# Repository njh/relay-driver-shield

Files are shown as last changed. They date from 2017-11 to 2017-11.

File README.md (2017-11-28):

Relay Driver Shield
===================

An Arduino shield for controlling four 12v relays.
The schematic and PCB layout were created using [KiCad](http://kicad-pcb.org/).

While it is designed for relays, it can be used for powering anything
that requires a bit more current or voltage.

| Arduino Pin | Function  |
|---|---|
| `D5` | Relay 1 |
| `D6` | Relay 2 |
| `D7` | Relay 3 |
| `D8` | Relay 4 |

The output voltage is determined by the input voltage on the Arduino Board - the `VIN` pin.

Schematic
---------

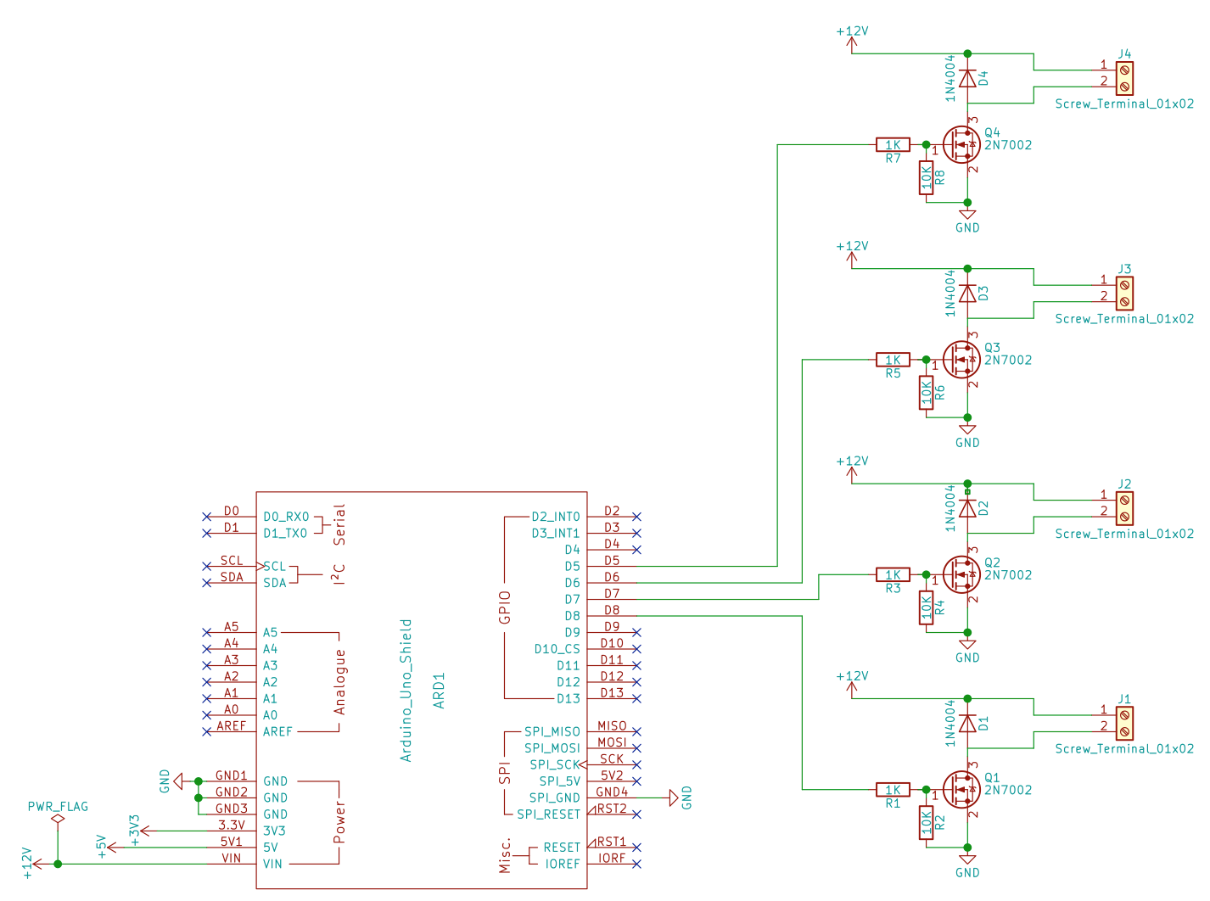
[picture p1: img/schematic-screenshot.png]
Schematic Screenshot


PCB Layout
----------

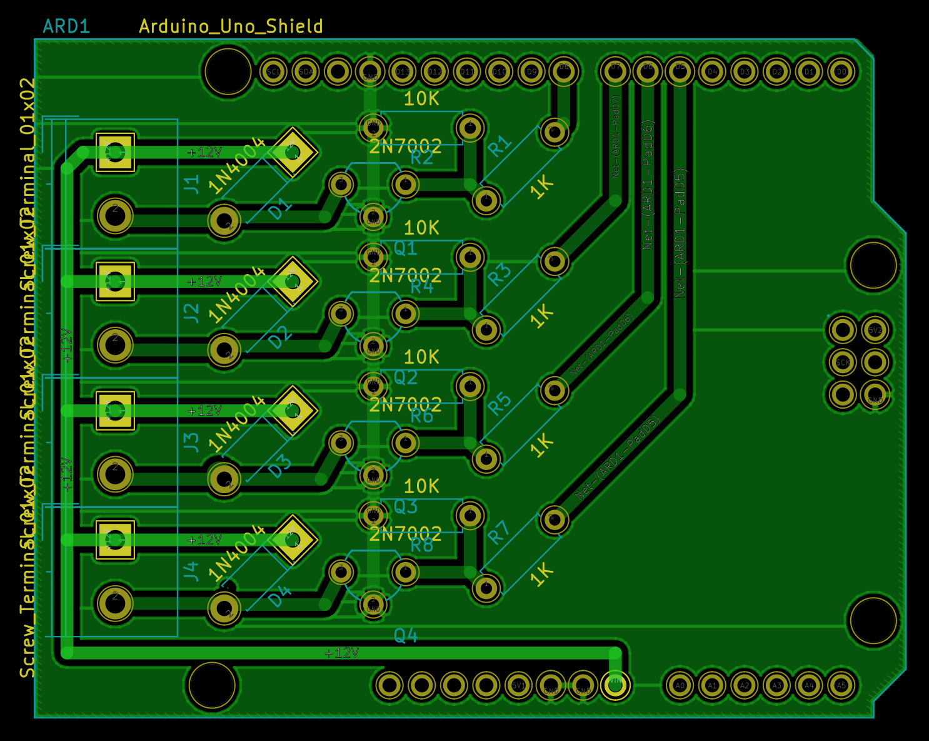
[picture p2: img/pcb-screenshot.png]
PCB Screenshot


Dependencies
------------

This shield makes use of the [Arduino KiCad Library](https://github.com/Alarm-Siren/arduino-kicad-library)
by [Nicholas Parks Young](https://github.com/alarm-siren).

License
-------

All of the files in this repository are licensed under
[Creative Commons Attribution Share-Alike License 4.0 CC-BY-SA](https://creativecommons.org/licenses/by-sa/4.0/).

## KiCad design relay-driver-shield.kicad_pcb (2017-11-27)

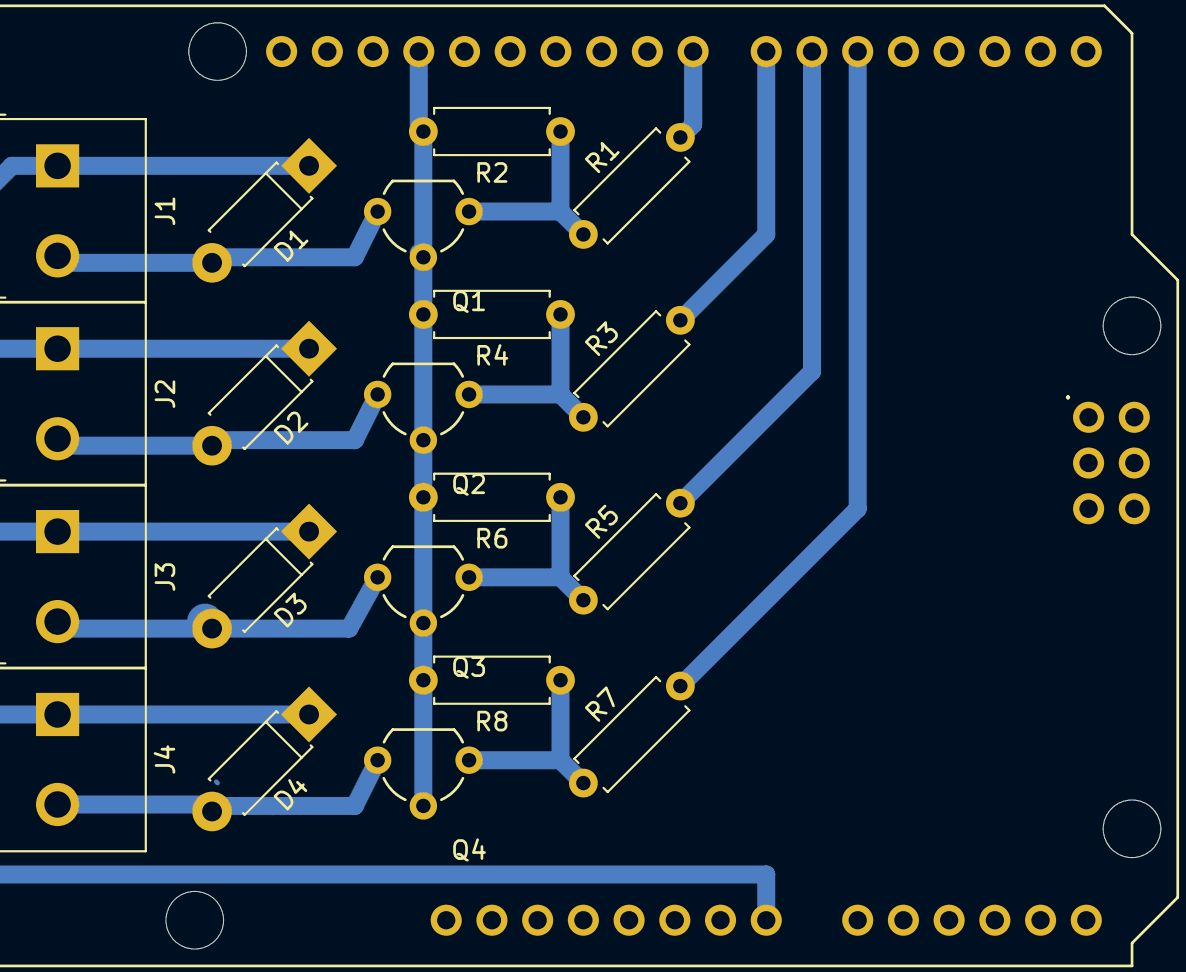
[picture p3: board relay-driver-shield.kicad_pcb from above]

Board: 2 copper layers, 21 parts (0 on the bottom side), 14 nets.

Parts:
ARD1: Arduino_Uno_Shield
D1, D2, D3, D4: 1N4004; D_DO-41_SOD81_P7.62mm_Horizontal
J1, J2, J3, J4: Screw_Terminal_01x02; TerminalBlock_Philmore_TB132_02x5mm_Straight
Q1, Q2, Q3, Q4: 2N7002; TO-92_Molded_Wide
R1, R3, R5, R7: 1K; R_Axial_DIN0207_L6.3mm_D2.5mm_P7.62mm_Horizontal
R2, R4, R6, R8: 10K; R_Axial_DIN0207_L6.3mm_D2.5mm_P7.62mm_Horizontal

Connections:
+12V: ARD1.VIN, D1.1, D2.1, D3.1, D4.1, J1.1, J2.1, J3.1, J4.1
GND: ARD1.GND1, ARD1.GND2, ARD1.GND3, ARD1.GND4, Q1.2, Q2.2, Q3.2, Q4.2, R2.2, R4.2, R6.2, R8.2
unnamed: ARD1.D5, R7.2
unnamed: ARD1.D6, R5.2
unnamed: ARD1.D7, R3.2
unnamed: ARD1.D8, R1.2
unnamed: D1.2, J1.2, Q1.3
unnamed: D2.2, J2.2, Q2.3
unnamed: D3.2, J3.2, Q3.3
unnamed: D4.2, J4.2, Q4.3
unnamed: Q1.1, R1.1, R2.1
unnamed: Q2.1, R3.1, R4.1
unnamed: Q3.1, R5.1, R6.1
unnamed: Q4.1, R7.1, R8.1

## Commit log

2017-11-23 Added .gitignore for KiCad https://github.com/github/gitignore/blob/master/KiCad.gitignore
2017-11-23 Initial check in of Schematic
    [relay-driver-shield.sch]
2017-11-25 Switched from 01x08 Screw Terminal to 4x 01x02
    [relay-driver-shield.sch]
2017-11-25 Created PCB layout using pcbnew
    [relay-driver-shield.kicad_pcb]
2017-11-25 Removed bridge between GND1, GND2 and GND3 Not needed and avoids problems with Electrical Rule Checker
    [relay-driver-shield.kicad_pcb, relay-driver-shield.sch]
2017-11-26 Added values to the resistors and diodes
    [relay-driver-shield.kicad_pcb, relay-driver-shield.sch]
2017-11-26 Moved components closer together on PCB
    [relay-driver-shield.kicad_pcb]
2017-11-27 Added copper fill to bottom
    [relay-driver-shield.kicad_pcb, relay-driver-shield.sch]
2017-11-27 Added arduino-kicad-library as a sub-module to the project
2017-11-28 Updated arduino-kicad-library to v1.1 tag
